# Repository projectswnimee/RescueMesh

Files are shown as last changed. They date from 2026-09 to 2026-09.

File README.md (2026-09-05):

<div align="center">

# RescueMesh

**ESP32 and LoRa emergency messaging for flood and disaster response**

**Semi-finalist — SL IoT competition, Sri Lanka**






</div>

<p align="center">
  <a href="docs/images/rescuemesh-prototype.png">
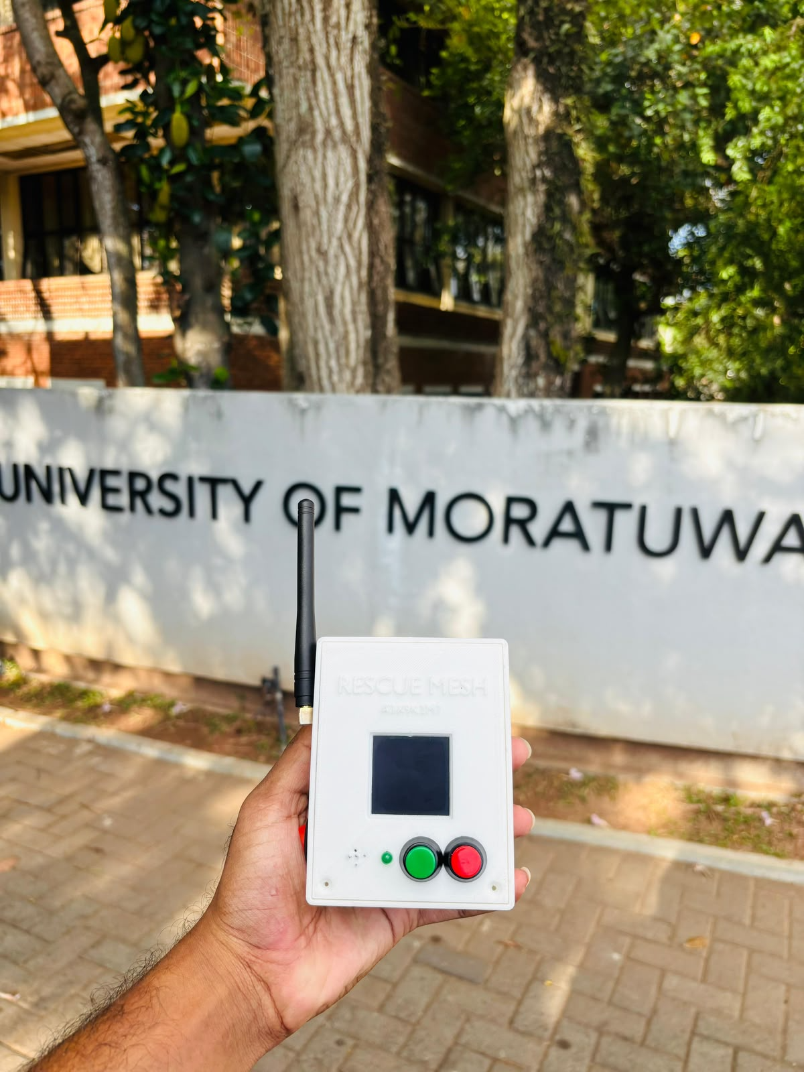
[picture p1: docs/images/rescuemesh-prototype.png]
RescueMesh handheld prototype with antenna, display and control buttons
    
  </a>
  <br>
  <sub>Original prototype photograph supplied by project collaborator Nimesha Nanayakkara. Click to view full size.</sub>
</p>

RescueMesh explores how battery-powered nodes can exchange SOS messages when
normal connectivity is unavailable. ESP32 controllers communicate through
AS32-TTL-100 LoRa radios, with progressive experiments covering broadcast,
relay forwarding, duplicate suppression, TTL and gateway uploads.

This is Nimesha Nanayakkara's maintained copy of the collaborative project.
The [original team repository](https://github.com/HiranGeeth/RescueMesh-Disaster-Rescue_Long-Range-Communication-System),
original MIT licence and hardware-author credits are preserved through explicit
[source attribution](ATTRIBUTION.md).

## System overview

```text
SOS button / Bluetooth input
            ↓
ESP32 field node ↔ LoRa relay nodes ↔ gateway receiver
                                           ↓
                                  Wi-Fi → test backend

Power-path PCB + battery supply + enclosure support the node hardware.
```

The checked-in firmware implements custom messaging over LoRa modules.
An operational LoRaWAN network server and LoRaWAN compliance are not demonstrated.

## Included implementation

| Area | Source and assets |
|---|---|
| Firmware experiments | [test_codes/](test_codes/) — UART, parameter configuration, point-to-point and broadcast messaging |
| Relay behaviour | Deduplication, time windows, TTL, randomized retransmission and rebroadcast tests |
| User interaction | SOS button handling and Bluetooth-to-node experiments |
| Gateway integration | LoRa reception and Wi-Fi upload to a configurable test endpoint |
| Power electronics | [Power-path circuit](hardware/Power%20Path%20Management%20Circuit/) — KiCad schematic/PCB, circuit image and fabrication PDFs |
| Mechanical design | [Enclosure](hardware/Enclosure/) — Blender, STL, Cura and printer-specific G-code assets |
| Coverage studies | [MATLAB simulations](matlab_simulations/) — terrain, coverage and routing experiments |

## Hardware design previews

<p align="center">
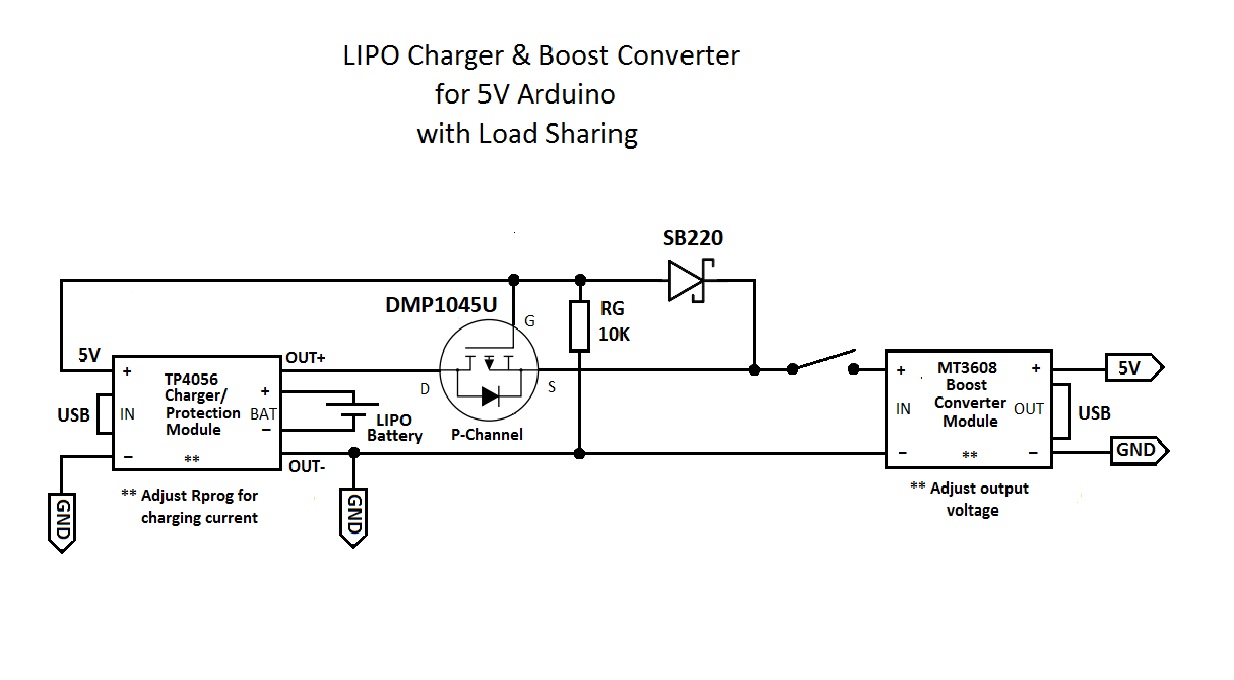
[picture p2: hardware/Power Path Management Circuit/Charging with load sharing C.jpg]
RescueMesh power-path circuit design
  
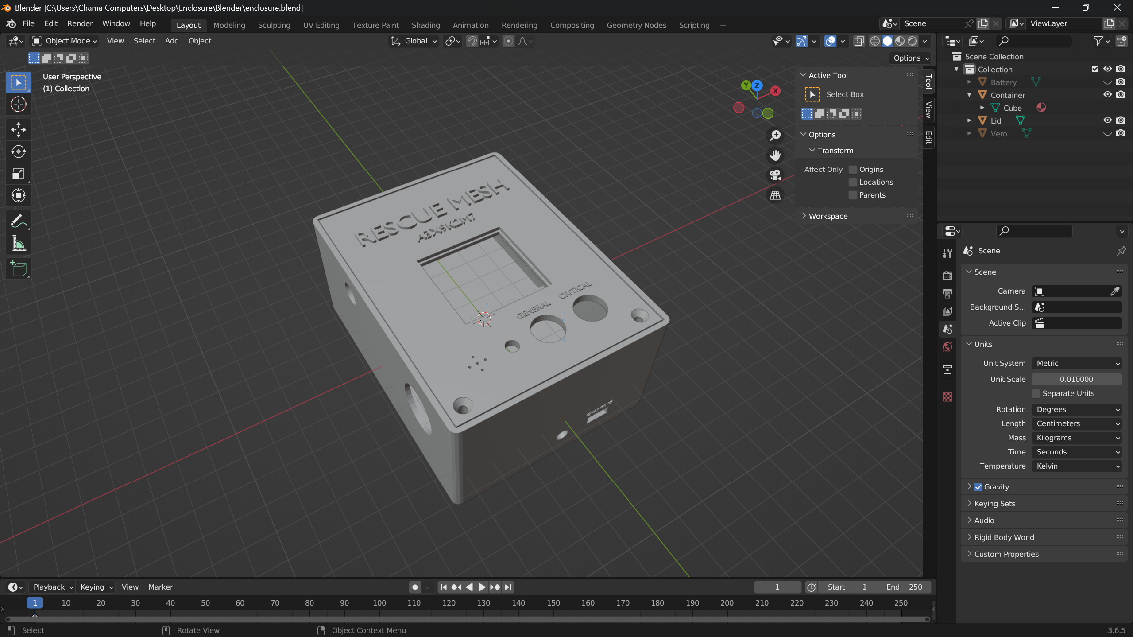
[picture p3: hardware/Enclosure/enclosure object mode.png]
RescueMesh enclosure design preview
  
</p>

These are design assets. The power-path and enclosure documentation credits
**Lasindu Viduranga**. The photograph above documents the assembled prototype;
calibrated power measurements and repeatable field-range data still need to
be added with their test conditions.

## Getting started

1. Clone this repository:

   ```bash
   git -c core.longpaths=true clone https://github.com/projectswnimee/RescueMesh.git
   ```

2. Use Arduino IDE with the ESP32 board support installed. Choose the board
   matching your ESP32 development module.
3. Start with [the GPIO/UART test](test_codes/Code_1.0_GPIO_UART_Test/1.0_GPIO_UART_Test.ino).
   Read the selected sketch's pin definitions before connecting the radio.
4. Progress through parameter read/write and point-to-point tests before using
   relay or field-node sketches. Match radio channel and air settings at both ends.
5. For the gateway upload test, copy
   [secrets.example.h](test_codes/Code_1.3.2.1_Gateway_Backend_Upload_Test/Reciever_Code/secrets.example.h)
   to `secrets.h` in the same sketch folder and enter your own Wi-Fi and endpoint
   values. That local file is ignored by Git.
6. Record the sketch, board package version, wiring, settings and serial logs
   with each experiment. Test one transmitter/receiver pair before adding relays.

The original directories and sketch filenames are retained for traceability.
Arduino IDE may offer to create a matching sketch folder for older filenames.

For `matlab_simulations/DEM.m`, set `OPENTOPOGRAPHY_API_KEY` in your local
environment if downloading new terrain data. Do not commit or print the key.

## Evidence and limits

- **Competition:** semi-finalist in the SL IoT competition, Sri Lanka, reported
  by project collaborator Nimesha Nanayakkara. The edition/year and official
  certificate or announcement are pending addition; see [attribution](ATTRIBUTION.md).
- **Radio:** range and power depend on antennas, configuration, environment and
  board design. Source claims such as 3 km or microamp sleep current are not
  presented here as independently measured whole-system results.
- **Security:** the field-node sketch contains a public demonstration key
  whitelist. This does not establish cryptographic authentication or confidentiality;
  an upstream filename containing “Encryption” is not evidence of secure encryption.
- **Readiness:** folder names such as `Production_Firmware` are inherited source
  labels. This copy has not been newly tested on physical hardware, and is not
  a certified emergency-response system.
- **Simulation:** terrain inputs and MATLAB outputs need their own provenance
  and validation; a coverage simulation does not establish field coverage.

## Collaboration and licence

Use branches and pull requests for new contributions. State your engineering
role and attach relevant measurements or design files. Uploading the shared
source does not confer sole authorship of the project.

See [ATTRIBUTION.md](ATTRIBUTION.md) for the source revision, documented
contributors and publication changes. The original [MIT licence](LICENSE)
and its copyright notice are retained unchanged.

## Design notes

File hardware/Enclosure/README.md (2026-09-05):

# 🧱 3D Printed Enclosure  
## Power Path Management Circuit Housing  

---

## 📌 Description
This enclosure is designed to securely house the **Power Path Management Circuit**, including the LiPo charger, boost converter, and related components.

### ✅ Key Features
- Physical protection  
- Compact organization of components  
- Easy access for USB input and output connections  

---

## 📁 Folder Structure
- **Blender File/** → Original `.blend` design file  
- **Stl/** → STL files for 3D printing  
- **Cura/** → Slicing files / configurations  
- **enclosure object mode.png** → Preview image of the enclosure  

---

## 🛠️ Design Details
- Designed using **Blender**  
- Optimized for **3D printing**  
- Compact and lightweight structure  

### 🔌 Openings
- USB input  
- 5V output  
- Ventilation (if applicable)  

---

## 🖨️ Printing Instructions
- **File format:** `.stl`  
- **Recommended material:** PLA  

### ⚙️ Suggested Settings
- Layer height: 0.2 mm  
- Infill: 20–40%  
- Supports: As required (depending on orientation)  

---

## ⚠️ Notes
- Ensure proper alignment before printing  
- Check tolerances based on your printer accuracy  
- Modify design if your components differ in size  

---

## 🧠 Applications
- Embedded systems enclosure  
- Arduino / IoT projects  
- Portable electronics housing  

---

## 👨‍💻 Author
**Lasindu Viduranga**  
📧 wplvidu@gmail.com  

**Team Member**  
Rescue Mesh

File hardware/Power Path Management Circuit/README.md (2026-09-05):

# 🔋 Power Path Management Circuit  
## LiPo Charger + Boost Converter with Load Sharing (5V Output)

---

## 📌 Description
This module implements a **power path management system** that allows a device (e.g., Arduino, ESP32) to be powered while simultaneously charging a LiPo battery.

### ✅ Key Features
- Safe battery charging  
- Automatic load sharing between USB input and battery  
- Stable 5V output using a boost converter  

---

## ⚙️ How It Works
- The **TP4056 module** charges the LiPo battery from a 5V USB input  
- A **P-channel MOSFET (DMP1045U)** controls power flow  

### 🔌 Operation Modes
**When USB is connected:**
- Load is powered directly from USB  
- Battery charges simultaneously  

**When USB is disconnected:**
- Battery supplies power to the load  

- The **MT3608 boost converter** steps battery voltage up to a stable **5V output**

---

## 🧩 Components Used
- TP4056 LiPo Charger Module (with protection)  
- LiPo Battery (3.7V)  
- DMP1045U P-Channel MOSFET  
- SB220 Schottky Diode  
- 10kΩ Resistor  
- MT3608 Boost Converter Module  

---

## 📁 Files Included
- **schematics/** → Circuit diagram files  
- **pcb/** → PCB design files (Gerber, layout)  

---

## 🔌 Input & Output
- **Input:** 5V (USB)  
- **Battery:** 3.7V LiPo  
- **Output:** Regulated 5V  

---

## ⚠️ Notes
- Adjust **Rprog** on TP4056 to set charging current  
- Adjust **MT3608** to get exact 5V output before connecting load  
- Ensure proper heat dissipation for high current usage  

---

## 🧠 Applications
- Arduino & Embedded Systems  
- Portable electronics  
- IoT devices with battery backup  

---

## 👨‍💻 Author
**Lasindu Viduranga**  
📧 wplvidu@gmail.com  

**Team Member**  
Rescue Mesh

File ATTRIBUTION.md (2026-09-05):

# Source and contributions

RescueMesh is collaborative engineering work. This repository is maintained by
Nimesha Nanayakkara (`projectswnimee`) as an authorized project copy.

## Original source

- [Team repository](https://github.com/HiranGeeth/RescueMesh-Disaster-Rescue_Long-Range-Communication-System)
- Imported source revision: `a151df3` (see the upstream history for full authorship)
- Original [MIT licence](LICENSE): copyright 2025 Hiran Geeth, preserved unchanged

The upstream commit history credits Hiran Geeth / Hiran Geeth Dharmapala and
Lasindu Viduranga. The hardware documentation explicitly credits Lasindu
Viduranga for the power-path circuit and enclosure work. Those credits remain
in their original files.

## This publication

This repository starts with a reviewed source snapshot instead of copying the
upstream history, which contains hard-coded credentials. The publication work
covers README organization, source attribution, local-configuration examples,
and competition recognition. A new import commit does not imply sole authorship
of the firmware, PCB, enclosure or simulations.

Individual engineering roles beyond those documented above will be recorded
when confirmed by the team. No roles have been assigned based on who uploaded
the repository.

## Recognition

Semi-finalist in the SL IoT competition, Sri Lanka, as reported by project
collaborator Nimesha Nanayakkara. The edition/year and certificate or official
announcement are not yet included in this repository.

## Publication changes

- Replaced Wi-Fi credentials and a webhook endpoint with an ignored local
  `secrets.h` and a committed `secrets.example.h` template.
- Replaced the field-node key whitelist with clearly labelled demonstration keys.
- Moved the terrain-download API key to `OPENTOPOGRAPHY_API_KEY` in the local environment.
- Retained the original source folders and hardware design assets.
- Excluded local KiCad preference/cache files through `.gitignore`.
- Corrected the project description to distinguish custom LoRa messaging from
  a verified LoRaWAN implementation, and separated design claims from measurements.

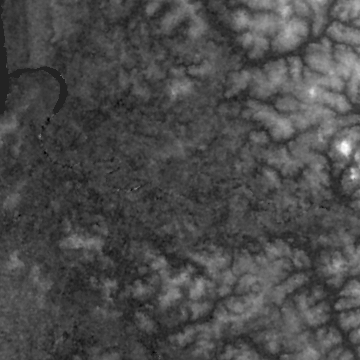
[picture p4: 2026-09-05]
matlab_simulations/DEM_SRTMGL1.tif

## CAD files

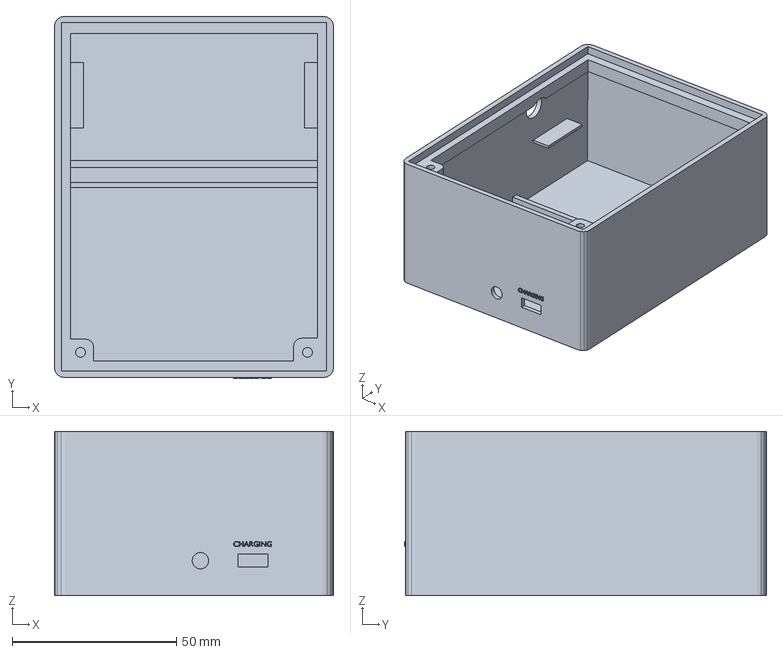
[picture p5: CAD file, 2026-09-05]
hardware/Enclosure/Cura/container.3mf
85.0 x 110.4 x 50.0 mm

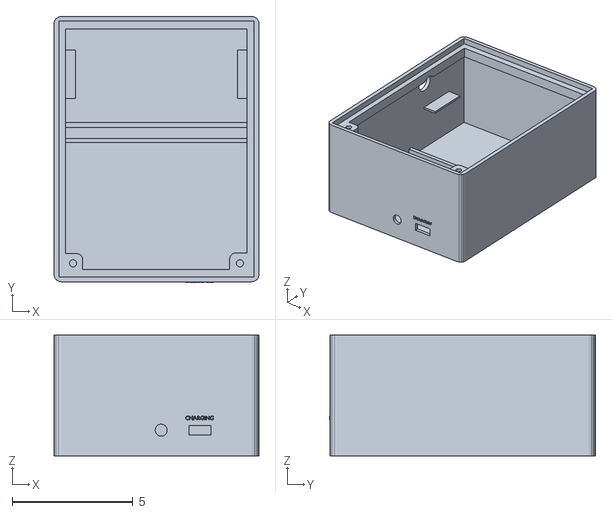
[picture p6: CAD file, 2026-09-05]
hardware/Enclosure/Stl/container.stl
8.50 x 11.0 x 5.00

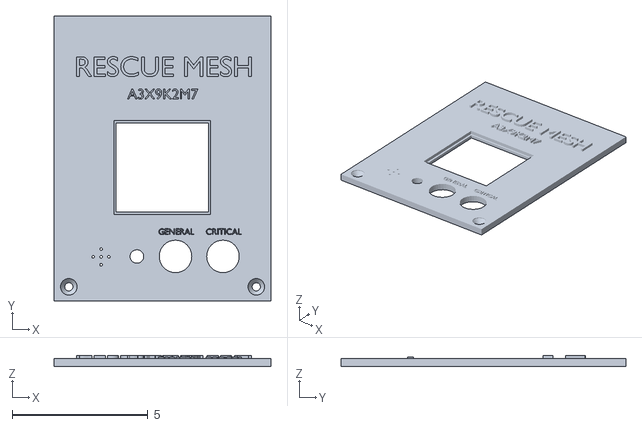
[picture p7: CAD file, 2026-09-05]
hardware/Enclosure/Stl/lid.stl
8.00 x 10.5 x 0.417

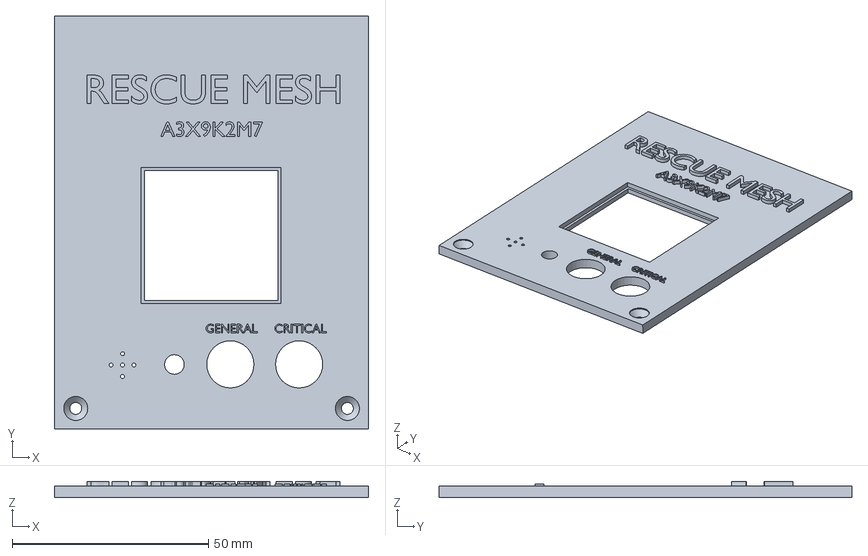
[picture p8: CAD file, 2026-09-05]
hardware/Enclosure/Cura/lid.3mf
80.0 x 105.1 x 4.17 mm

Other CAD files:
hardware/Enclosure/Cura/CE3V3SE_container v2.3mf
hardware/Enclosure/Stl/container v2.stl
hardware/Enclosure/Blender File/enclosure.blend

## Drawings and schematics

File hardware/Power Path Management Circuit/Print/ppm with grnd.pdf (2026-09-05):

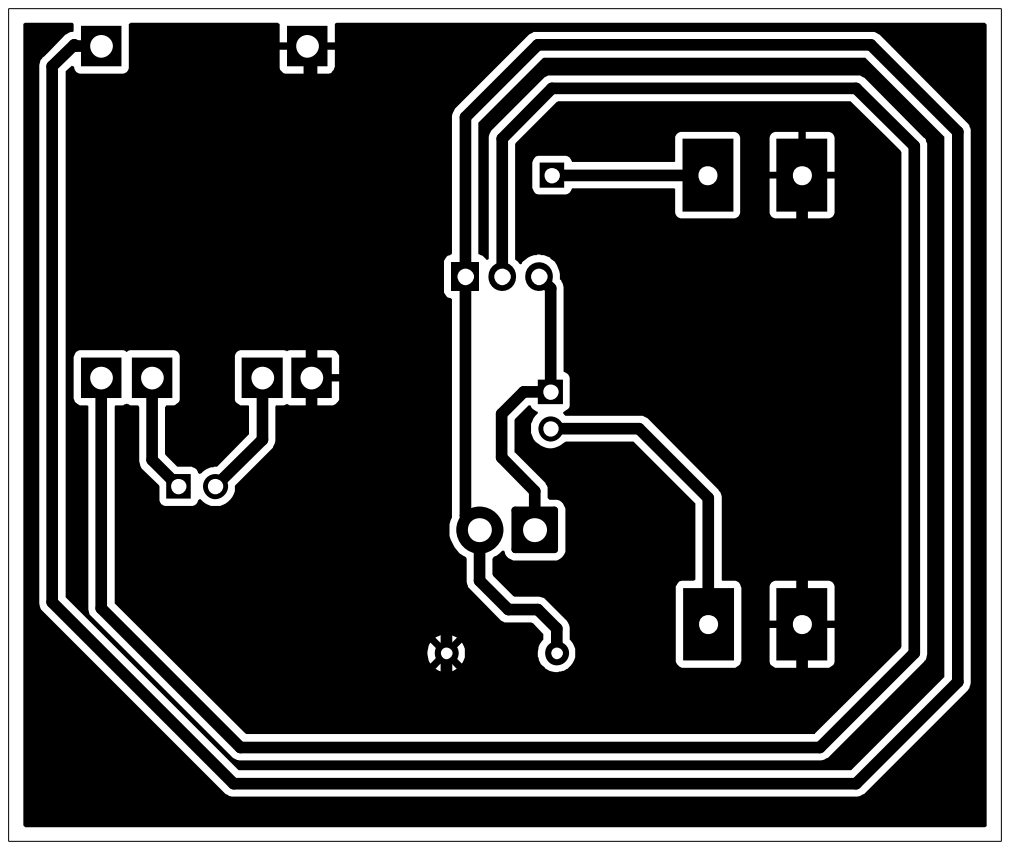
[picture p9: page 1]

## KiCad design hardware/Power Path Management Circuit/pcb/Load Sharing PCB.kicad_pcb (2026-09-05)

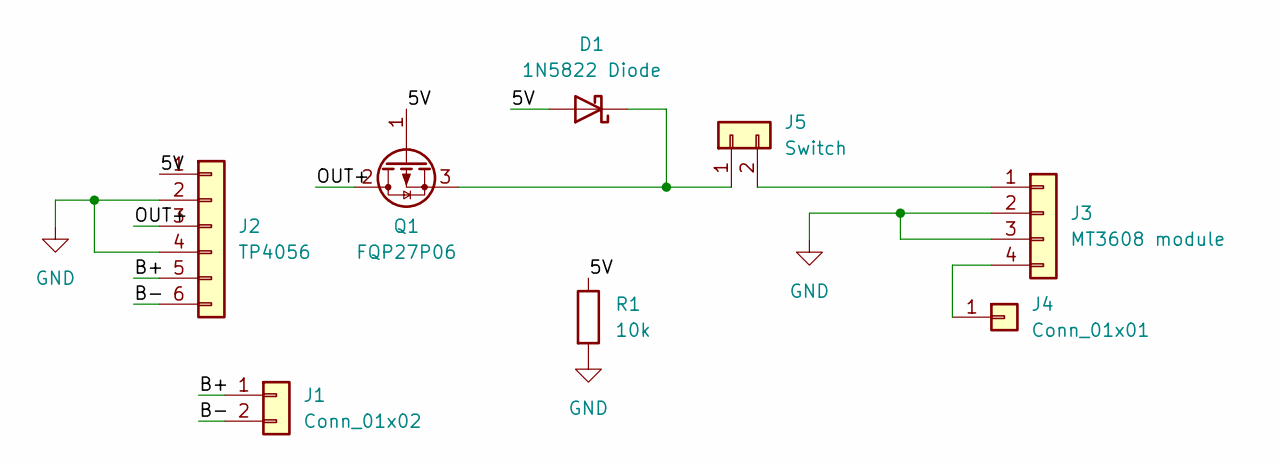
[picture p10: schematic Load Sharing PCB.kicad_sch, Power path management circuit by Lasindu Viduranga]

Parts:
D1: 1N5822 Diode; D_DO-201AD_P3.81mm_Vertical_AnodeUp
J1: Conn_01x02; PinHeader_1x02_P2.54mm_Vertical
J2: TP4056; TP4056-18650
J3: MT3608 module; MT3608_module
J4: Conn_01x01; PinHeader_1x01_P2.54mm_Vertical
J5: Switch; PinHeader_1x02_P2.54mm_Horizontal
Q1: FQP27P06; TO-220-3_Vertical
R1: 10k; R_Axial_DIN0207_L6.3mm_D2.5mm_P7.62mm_Horizontal

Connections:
/5V: D1.2 (A), J2.1, Q1.1 (G), R1.1
/B+: J1.1, J2.5
/B-: J1.2, J2.6
/OUT+: J2.3, Q1.2 (D)
GND: J2.2, J2.4, J3.2, J3.3, R1.2
unnamed: D1.1 (K), J5.1, Q1.3 (S)
unnamed: J3.1, J5.2
unnamed: J3.4, J4.1

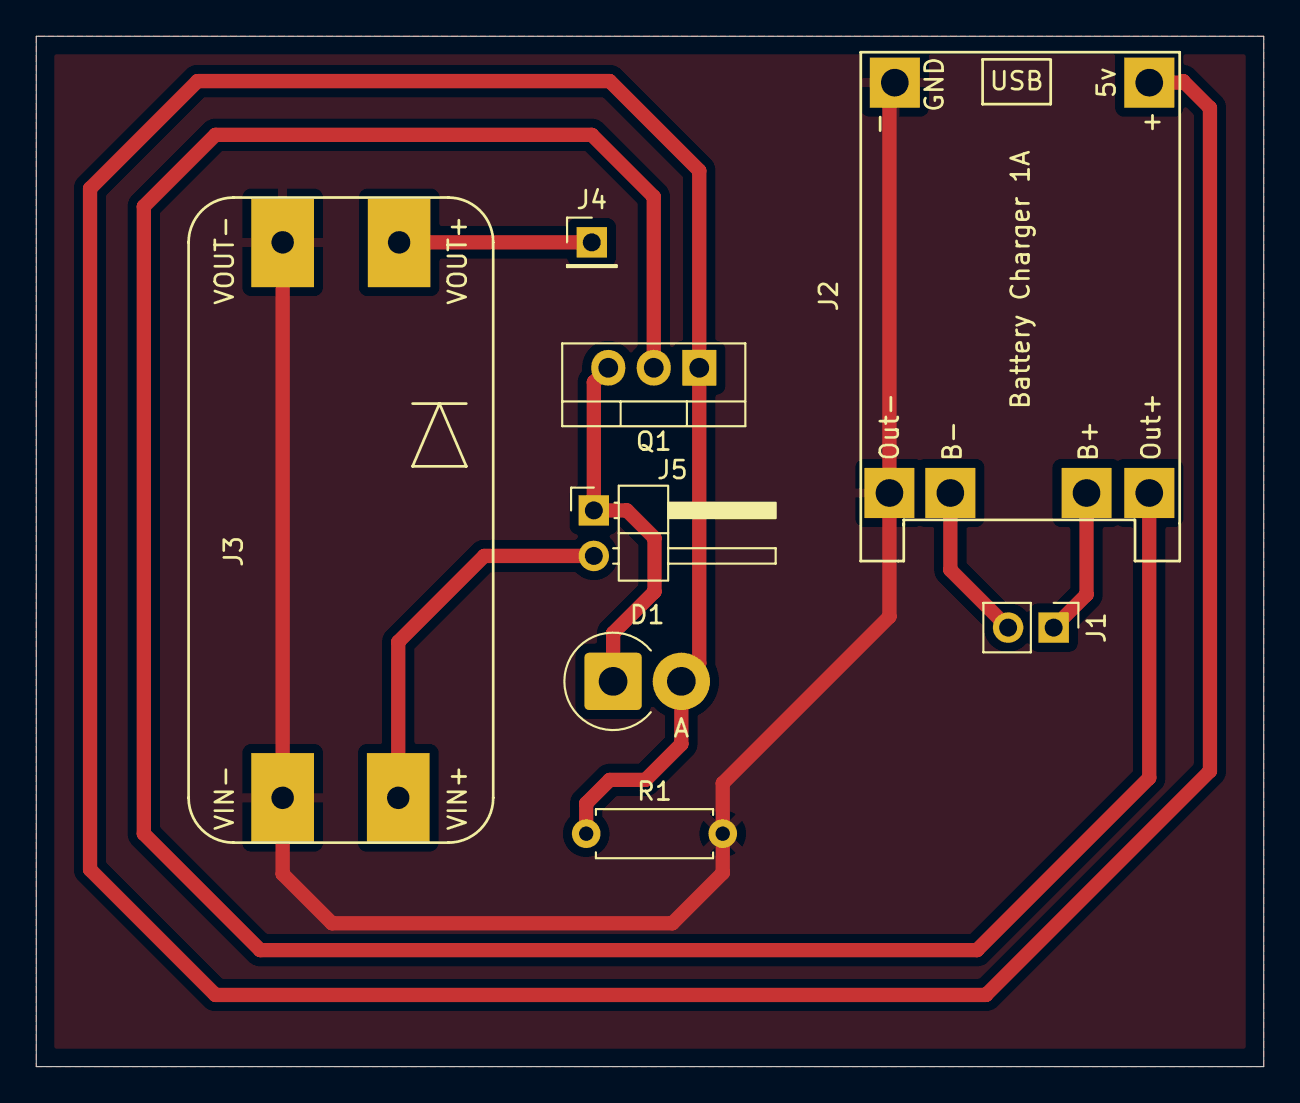
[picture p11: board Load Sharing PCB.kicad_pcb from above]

Board: 2 copper layers, 68.5 x 57.5 mm, 8 parts (0 on the bottom side), 8 nets.

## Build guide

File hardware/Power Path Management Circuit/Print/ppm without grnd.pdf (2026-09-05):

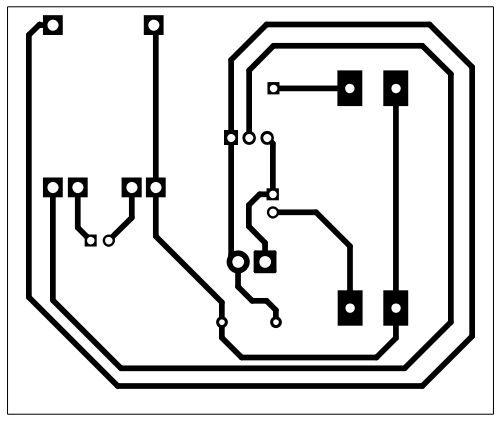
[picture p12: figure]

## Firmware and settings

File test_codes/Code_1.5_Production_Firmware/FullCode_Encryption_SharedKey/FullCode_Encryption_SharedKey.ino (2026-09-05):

/* ============================================================
   FloodGuard AIoT — Field Node v4.3 (SIMPLE BUTTON PRESS)
   ============================================================
   BEHAVIOR:
   - GENERAL button: Press once → sends ONE alert
   - CRITICAL button: Press once → sends ONE alert
   - NO auto-repeat, NO toggle mode
   - Each press sends exactly ONE message
   ============================================================ */

#include <Arduino.h>
#include "BluetoothSerial.h"
#include <EEPROM.h>

/* ================= PINOUT ================= */
#define LORA_TX       17
#define LORA_RX       16
#define LORA_MD0      25
#define LORA_MD1      26
#define BTN_GENERAL   33
#define BTN_CRITICAL  32
#define LED_STATUS    2
#define LED_REPLY     4

HardwareSerial LoRaSerial(2);
BluetoothSerial SerialBT;

/* ================= DEMONSTRATION WHITELIST ================= */
// Public examples only. These identifiers do not provide secure authentication.
const String VALID_KEYS[] = {
  "DEMO0001",   // NODE 01
  "DEMO0002",   // NODE 02
  "DEMO0003",   // NODE 03
  "DEMO0004",   // NODE 04
  "DEMO0005"    // NODE 05
};
const int VALID_KEY_COUNT = 5;

/* ================= NODE CONFIG ================= */
String NODE_KEY = "";
String NODE_NUMBER = "";
bool NODE_REGISTERED = false;
String LATITUDE = "6.9271";
String LONGITUDE = "79.8612";

// EEPROM addresses
#define EEPROM_KEY_ADDR    0
#define EEPROM_KEY_LEN     16
#define EEPROM_REG_FLAG    32

/* ================= MESSAGE CONFIG ================= */
uint8_t seqCounter = 1;
const int DEFAULT_TTL = 5;

/* ================= BUFFERS ================= */
String rxBuffer = "";

/* ================= DEDUP ================= */
String dedupList[30];
uint8_t dedupIndex = 0;

/* ================= BUTTON STATE ================= */
bool lastGeneralState = HIGH;
bool lastCriticalState = HIGH;

/* ================= DEBOUNCE ================= */
unsigned long lastGeneralDebounce = 0;
unsigned long lastCriticalDebounce = 0;
const unsigned long DEBOUNCE_DELAY = 200;

/* ================= LED PATTERNS ================= */
enum LEDPattern {
  LED_NORMAL,
  LED_SENDING,
  LED_REPLY_RECEIVED,
  LED_INTRUDER
};
LEDPattern currentPattern = LED_NORMAL;
unsigned long lastLedBlink = 0;
int intruderCount = 0;

/* ============================================================
   KEY VALIDATION
   ============================================================ */

bool isValidNodeKey(String key) {
  for (int i = 0; i < VALID_KEY_COUNT; i++) {
    if (VALID_KEYS[i] == key) return true;
  }
  return false;
}

void logIntruder(String key) {
  intruderCount++;
  Serial.println("╔═══════════════════════════════════════╗");
  Serial.println("║   ⚠️ INTRUDER ALERT ⚠️                 ║");
  Serial.println("╠═══════════════════════════════════════╣");
  Serial.print("║ INVALID KEY: ");
  Serial.println(key);
  Serial.print("║ COUNT:       ");
  Serial.println(String(intruderCount));
  Serial.println("╚═══════════════════════════════════════╝");
  currentPattern = LED_INTRUDER;
  lastLedBlink = millis();
}

/* ============================================================
   SYMBOL ENCRYPTION/DECRYPTION
   ============================================================ */

String encryptPayload(String plain) {
  String encrypted = "";
  for (int i = 0; i < plain.length(); i++) {
    char c = plain.charAt(i);
    switch (c) {
      case 'A': case 'a': encrypted += "@!"; break;
      case 'B': case 'b': encrypted += "#$"; break;
      case 'C': case 'c': encrypted += "%^"; break;
      case 'D': case 'd': encrypted += "&*"; break;
      case 'E': case 'e': encrypted += "(-"; break;
      case 'F': case 'f': encrypted += ")+"; break;
      case 'G': case 'g': encrypted += "[="; break;
      case 'H': case 'h': encrypted += "]{"; break;
      case 'I': case 'i': encrypted += "}|"; break;
      case 'J': case 'j': encrypted += "\\:"; break;
      case 'K': case 'k': encrypted += ";'"; break;
      case 'L': case 'l': encrypted += "\"<"; break;
      case 'M': case 'm': encrypted += ">?"; break;
      case 'N': case 'n': encrypted += "/~"; break;
      case 'O': case 'o': encrypted += "`1"; break;
      case 'P': case 'p': encrypted += "2@"; break;
      case 'Q': case 'q': encrypted += "3#"; break;
      case 'R': case 'r': encrypted += "4$"; break;
      case 'S': case 's': encrypted += "5%"; break;
      case 'T': case 't': encrypted += "6^"; break;
      case 'U': case 'u': encrypted += "7&"; break;
      case 'V': case 'v': encrypted += "8*"; break;
      case 'W': case 'w': encrypted += "9("; break;
      case 'X': case 'x': encrypted += "0)"; break;
      case 'Y': case 'y': encrypted += "-="; break;
      case 'Z': case 'z': encrypted += "+="; break;
      case '0': encrypted += "aa"; break;
      case '1': encrypted += "bb"; break;
      case '2': encrypted += "cc"; break;
      case '3': encrypted += "dd"; break;
      case '4': encrypted += "ee"; break;
      case '5': encrypted += "ff"; break;
      case '6': encrypted += "gg"; break;
      case '7': encrypted += "hh"; break;
      case '8': encrypted += "ii"; break;
      case '9': encrypted += "jj"; break;
      case '!': encrypted += "kk"; break;
      case '?': encrypted += "ll"; break;
      case '.': encrypted += "mm"; break;
      case ',': encrypted += "nn"; break;
      case ':': encrypted += "oo"; break;
      case ';': encrypted += "pp"; break;
      case ' ': encrypted += "**"; break;
      default:  encrypted += "??"; break;
    }
  }
  return encrypted;
}

String decryptPayload(String enc) {
  String decrypted = "";
  for (int i = 0; i + 1 < enc.length(); i += 2) {
    String sym = enc.substring(i, i + 2);
    if      (sym == "@!") decrypted += "A";
    else if (sym == "#$") decrypted += "B";
    else if (sym == "%^") decrypted += "C";
    else if (sym == "&*") decrypted += "D";
    else if (sym == "(-") decrypted += "E";
    else if (sym == ")+") decrypted += "F";
    else if (sym == "[=") decrypted += "G";
    else if (sym == "]{") decrypted += "H";
    else if (sym == "}|") decrypted += "I";
    else if (sym == "\\:") decrypted += "J";
    else if (sym == ";'") decrypted += "K";
    else if (sym == "\"<") decrypted += "L";
    else if (sym == ">?") decrypted += "M";
    else if (sym == "/~") decrypted += "N";
    else if (sym == "`1") decrypted += "O";
    else if (sym == "2@") decrypted += "P";
    else if (sym == "3#") decrypted += "Q";
    else if (sym == "4$") decrypted += "R";
    else if (sym == "5%") decrypted += "S";
    else if (sym == "6^") decrypted += "T";
    else if (sym == "7&") decrypted += "U";
    else if (sym == "8*") decrypted += "V";
    else if (sym == "9(") decrypted += "W";
    else if (sym == "0)") decrypted += "X";
    else if (sym == "-=") decrypted += "Y";
    else if (sym == "+=") decrypted += "Z";
    else if (sym == "aa") decrypted += "0";
    else if (sym == "bb") decrypted += "1";
    else if (sym == "cc") decrypted += "2";
    else if (sym == "dd") decrypted += "3";
    else if (sym == "ee") decrypted += "4";
    else if (sym == "ff") decrypted += "5";
    else if (sym == "gg") decrypted += "6";
    else if (sym == "hh") decrypted += "7";
    else if (sym == "ii") decrypted += "8";
    else if (sym == "jj") decrypted += "9";
    else if (sym == "kk") decrypted += "!";
    else if (sym == "ll") decrypted += "?";
    else if (sym == "mm") decrypted += ".";
    else if (sym == "nn") decrypted += ",";
    else if (sym == "oo") decrypted += ":";
    else if (sym == "pp") decrypted += ";";
    else if (sym == "**") decrypted += " ";
    else                  decrypted += "?";
  }
  return decrypted;
}

/* ============================================================
   EEPROM STORAGE
   ============================================================ */

void saveNodeToEEPROM() {
  for (int i = 0; i < EEPROM_KEY_LEN; i++) {
    EEPROM.write(EEPROM_KEY_ADDR + i, 0);
  }
  for (int i = 0; i < NODE_KEY.length() && i < EEPROM_KEY_LEN; i++) {
    EEPROM.write(EEPROM_KEY_ADDR + i, NODE_KEY[i]);
  }
  EEPROM.write(EEPROM_REG_FLAG, 1);
  EEPROM.commit();
  Serial.print("[EEPROM] Node key saved: ");
  Serial.println(NODE_KEY);
}

void loadNodeFromEEPROM() {
  EEPROM.begin(512);
  byte registered = EEPROM.read(EEPROM_REG_FLAG);
  
  if (registered == 1) {
    char keyBuf[EEPROM_KEY_LEN + 1];
    bool hasValidKey = false;
    
    for (int i = 0; i < EEPROM_KEY_LEN; i++) {
      char c = EEPROM.read(EEPROM_KEY_ADDR + i);
      if (c >= 'A' && c <= 'Z' || c >= '0' && c <= '9') {
        keyBuf[i] = c;
        hasValidKey = true;
      } else {
        keyBuf[i] = '\0';
        break;
      }
    }
    keyBuf[EEPROM_KEY_LEN] = '\0';
    
    if (hasValidKey && String(keyBuf).length() >= 6) {
      NODE_KEY = String(keyBuf);
      NODE_NUMBER = "Node_" + NODE_KEY.substring(0, 4);
      NODE_REGISTERED = true;
      Serial.print("✓ Loaded from EEPROM: ");
      Serial.println(NODE_KEY);
    } else {
      NODE_REGISTERED = false;
    }
  }
}

/* ============================================================
   REGISTRATION
   ============================================================ */

void registerNode() {
  Serial.println("\n╔═══════════════════════════════════════╗");
  Serial.println("║   NODE NOT REGISTERED                 ║");
  Serial.println("║   Valid keys:                         ║");
  for (int i = 0; i < VALID_KEY_COUNT; i++) {
    Serial.print("║     ");
    Serial.println(VALID_KEYS[i]);
  }
  Serial.println("║                                       ║");
  Serial.println("║   Enter 8-char key from above:        ║");
  Serial.println("╚═══════════════════════════════════════╝");
  Serial.print("Enter key: ");
  
  unsigned long startTime = millis();
  String inputKey = "";
  bool inputComplete = false;
  
  while (millis() - startTime < 60000) {
    if (Serial.available()) {
      char c = Serial.read();
      if (c == '\n' || c == '\r') {
        if (inputKey.length() > 0) {
          inputComplete = true;
          break;
        }
      } else if ((c >= 'A' && c <= 'Z') || (c >= '0' && c <= '9')) {
        inputKey += c;
        Serial.print(c);
      }
    }
    delay(10);
  }
  
  if (inputComplete && isValidNodeKey(inputKey)) {
    NODE_KEY = inputKey;
    NODE_NUMBER = "Node_" + NODE_KEY.substring(0, 4);
    NODE_REGISTERED = true;
    saveNodeToEEPROM();
    
    Serial.println();
    Serial.println("✓ Registration successful!");
    Serial.print("  KEY: ");
    Serial.println(NODE_KEY);
    Serial.print("  NAME: ");
    Serial.println(NODE_NUMBER);
    delay(2000);
  } else {
    Serial.println();
    Serial.println("✗ Invalid key! Restart to try again.");
    while(1) {
      digitalWrite(LED_STATUS, HIGH);
      delay(200);
      digitalWrite(LED_STATUS, LOW);
      delay(200);
    }
  }
}

/* ============================================================
   BLUETOOTH SETUP
   ============================================================ */

void setupBluetooth() {
  String btName = "FloodGuard_User";
  
  if (NODE_REGISTERED && NODE_KEY.length() > 0) {
    String uniqueId = NODE_KEY.substring(NODE_KEY.length() - 4);
    btName = "FloodGuard_" + uniqueId;
  }
  
  SerialBT.begin(btName);
  
  Serial.print("[BLUETOOTH] Name: ");
  Serial.println(btName);
  Serial.println("[BLUETOOTH] Ready to pair. No PIN required.");
}

/* ============================================================
   LED STATUS
   ============================================================ */

void updateLED() {
  unsigned long now = millis();
  
  switch (currentPattern) {
    case LED_NORMAL:
      digitalWrite(LED_STATUS, HIGH);
      digitalWrite(LED_REPLY, LOW);
      break;
      
    case LED_SENDING:
      if (now - lastLedBlink < 100) digitalWrite(LED_STATUS, HIGH);
      else if (now - lastLedBlink < 200) digitalWrite(LED_STATUS, LOW);
      else lastLedBlink = now;
      break;
      
    case LED_REPLY_RECEIVED:
      if (now - lastLedBlink < 500) {
        digitalWrite(LED_STATUS, HIGH);
        digitalWrite(LED_REPLY, HIGH);
      } else if (now - lastLedBlink < 1000) {
        digitalWrite(LED_STATUS, LOW);
        digitalWrite(LED_REPLY, LOW);
      } else {
        currentPattern = LED_NORMAL;
      }
      break;
      
    case LED_INTRUDER:
      if (now - lastLedBlink < 100) digitalWrite(LED_STATUS, HIGH);
      else if (now - lastLedBlink < 200) digitalWrite(LED_STATUS, LOW);
      else if (now - lastLedBlink < 300) digitalWrite(LED_STATUS, HIGH);
      else if (now - lastLedBlink < 400) digitalWrite(LED_STATUS, LOW);
      else lastLedBlink = now;
      break;
  }
}

/* ============================================================
   DISPLAY REPLY
   ============================================================ */

void displayReply(String decryptedMessage, String msgId) {
  currentPattern = LED_REPLY_RECEIVED;
  lastLedBlink = millis();
  
  Serial.println("\n");
  Serial.println("╔══════════════════════════════════════════════════════════════╗");
  Serial.println("║                    📨 REPLY FROM RESCUE TEAM                  ║");
  Serial.println("╠══════════════════════════════════════════════════════════════╣");
  Serial.print("║ MSG ID:     ");
  Serial.println(msgId);
  Serial.print("║ TO NODE:    ");
  Serial.print(NODE_KEY);
  Serial.print(" (");
  Serial.print(NODE_NUMBER);
  Serial.println(")");
  Serial.println("╠══════════════════════════════════════════════════════════════╣");
  Serial.println("║ MESSAGE:                                                    ║");
  
  String remaining = decryptedMessage;
  while (remaining.length() > 50) {
    Serial.print("║ ");
    Serial.println(remaining.substring(0, 50));
    remaining = remaining.substring(50);
  }
  if (remaining.length() > 0) {
    Serial.print("║ ");
    Serial.println(remaining);
  }
  
  Serial.println("╚══════════════════════════════════════════════════════════════╝");
  Serial.println();
  
  if (SerialBT.hasClient()) {
    SerialBT.print("REPLY: ");
    SerialBT.println(decryptedMessage);
  }
}

/* ============================================================
   DEDUP
   ============================================================ */

bool isDuplicate(String id) {
  for (int i = 0; i < 30; i++) {
    if (dedupList[i] == id) return true;
  }
  return false;
}

void storeDedupID(String id) {
  dedupList[dedupIndex] = id;
  dedupIndex = (dedupIndex + 1) % 30;
}

/* ============================================================
   SEND MESSAGE
   ============================================================ */

void sendLoRaMessage(String payload, String flag) {
  if (!NODE_REGISTERED) {
    Serial.println("[ERROR] Node not registered!");
    return;
  }
  
  currentPattern = LED_SENDING;
  lastLedBlink = millis();
  
  String seqStr = (seqCounter < 10) ? "0" + String(seqCounter) : String(seqCounter);
  seqCounter++;
  
  String encPayload = encryptPayload(payload);
  
  String fullMsg = "FG|" + NODE_KEY + "|" + seqStr + "|" + 
                   String(DEFAULT_TTL) + "|" + NODE_KEY + "|" +
                   flag + "|" + LATITUDE + "|" + LONGITUDE + "|" +
                   encPayload + "\n";
  
  LoRaSerial.write(fullMsg.c_str(), fullMsg.length());
  
  Serial.println("────────────────────────────────────────");
  Serial.print("[SENT] From: ");
  Serial.println(NODE_KEY);
  Serial.print("[FLAG] ");
  Serial.println(flag);
  Serial.print("[MSG ] ");
  Serial.println(payload);
  Serial.println("────────────────────────────────────────");
  
  delay(100);
  currentPattern = LED_NORMAL;
}

/* ============================================================
   BUTTON HANDLERS (SIMPLE — ONE PRESS = ONE MESSAGE)
   ============================================================ */

void handleButtons() {
  unsigned long now = millis();
  
  // Read current button states (LOW = pressed, because INPUT_PULLUP)
  bool currentGeneral = digitalRead(BTN_GENERAL);
  bool currentCritical = digitalRead(BTN_CRITICAL);
  
  // GENERAL BUTTON — Rising edge detection (released after press)
  if (lastGeneralState == LOW && currentGeneral == HIGH) {
    if (now - lastGeneralDebounce > DEBOUNCE_DELAY) {
      lastGeneralDebounce = now;
      sendLoRaMessage("General safety issue reported", "BTN_GENERAL");
      Serial.println("[BTN] GENERAL alert sent");
    }
  }
  lastGeneralState = currentGeneral;
  
  // CRITICAL BUTTON — Rising edge detection (released after press)
  if (lastCriticalState == LOW && currentCritical == HIGH) {
    if (now - lastCriticalDebounce > DEBOUNCE_DELAY) {
      lastCriticalDebounce = now;
      sendLoRaMessage("CRITICAL EMERGENCY SOS", "BTN_CRITICAL");
      Serial.println("[BTN] CRITICAL alert sent");
    }
  }
  lastCriticalState = currentCritical;
}

/* ============================================================
   PROCESS RECEIVED
   ============================================================ */

void processReceived(String raw) {
  raw.trim();
  if (raw.length() == 0) return;
  
  /* ========== HANDLE BACKEND REPLY ========== */
  if (raw.startsWith("FGR|")) {
    int p1 = raw.indexOf('|');
    int p2 = raw.indexOf('|', p1 + 1);
    int p3 = raw.indexOf('|', p2 + 1);
    
    if (p1 > 0 && p2 > p1 && p3 > p2) {
      String destKey = raw.substring(p1 + 1, p2);
      String msgId = raw.substring(p2 + 1, p3);
      String encPayload = raw.substring(p3 + 1);
      encPayload.trim();
      
      if (destKey == NODE_KEY) {
        String decrypted = decryptPayload(encPayload);
        displayReply(decrypted, msgId);
        Serial.println("[REPLY] ✅ For THIS node - DISPLAYED");
        return;
      } else if (isValidNodeKey(destKey)) {
        int delayMs = random(1000, 5001);
        delay(delayMs);
        LoRaSerial.write((raw + "\n").c_str(), raw.length() + 1);
        return;
      }
    }
    return;
  }
  
  /* ========== HANDLE LOCATION UPDATE ========== */
  if (raw.startsWith("LOC|")) {
    int p1 = raw.indexOf('|');
    int p2 = raw.indexOf('|', p1 + 1);
    int p3 = raw.indexOf('|', p2 + 1);
    
    if (p1 > 0 && p2 > p1 && p3 > p2) {
      String destKey = raw.substring(p1 + 1, p2);
      
      if (destKey == NODE_KEY) {
        LATITUDE = raw.substring(p2 + 1, p3);
        LONGITUDE = raw.substring(p3 + 1);
        Serial.print("[LOCATION] Updated: ");
        Serial.print(LATITUDE);
        Serial.print(", ");
        Serial.println(LONGITUDE);
        return;
      } else if (isValidNodeKey(destKey)) {
        int delayMs = random(1000, 5001);
        delay(delayMs);
        LoRaSerial.write((raw + "\n").c_str(), raw.length() + 1);
        return;
      }
    }
    return;
  }
  
  /* ========== HANDLE FIELD MESSAGE ========== */
  if (!raw.startsWith("FG|")) return;
  
  int p1 = raw.indexOf('|');
  int p2 = raw.indexOf('|', p1 + 1);
  int p3 = raw.indexOf('|', p2 + 1);
  int p4 = raw.indexOf('|', p3 + 1);
  int p5 = raw.indexOf('|', p4 + 1);
  int p6 = raw.indexOf('|', p5 + 1);
  int p7 = raw.indexOf('|', p6 + 1);
  int p8 = raw.indexOf('|', p7 + 1);
  
  if (p1 < 0 || p2 < 0 || p3 < 0 || p4 < 0 || p5 < 0 || p6 < 0 || p7 < 0 || p8 < 0) return;
  
  String nodeKey = raw.substring(p1 + 1, p2);
  String seqNo   = raw.substring(p2 + 1, p3);
  int    ttl     = raw.substring(p3 + 1, p4).toInt();
  String path    = raw.substring(p4 + 1, p5);
  String flag    = raw.substring(p5 + 1, p6);
  String lat     = raw.substring(p6 + 1, p7);
  String lon     = raw.substring(p7 + 1, p8);
  String payload = raw.substring(p8 + 1);
  
  if (!isValidNodeKey(nodeKey)) {
    logIntruder(nodeKey);
    return;
  }
  
  if (ttl <= 0) return;
  if (nodeKey == NODE_KEY) return;
  
  String dedupID = nodeKey + seqNo;
  if (isDuplicate(dedupID)) return;
  storeDedupID(dedupID);
  
  String newPath = path + ">" + NODE_KEY;
  int delayMs = random(1000, 5001);
  delay(delayMs);
  
  String relayMsg = "FG|" + nodeKey + "|" + seqNo + "|" +
                    String(ttl - 1) + "|" + newPath + "|" +
                    "RELAY" + "|" + lat + "|" + lon + "|" +
                    payload + "\n";
  
  LoRaSerial.write(relayMsg.c_str(), relayMsg.length());
}

/* ============================================================
   SETUP
   ============================================================ */
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
void loop() {
  handleButtons();
  updateLED();
  
  // Bluetooth input
  if (SerialBT.available()) {
    String btMsg = SerialBT.readStringUntil('\n');
    btMsg.trim();
    if (btMsg.length() > 0 && btMsg.length() < 200) {
      sendLoRaMessage(btMsg, "BT");
      Serial.print("[BT] Sent: ");
      Serial.println(btMsg);
      SerialBT.print("Sent: ");
      SerialBT.println(btMsg);
    }
  }
  
  // Serial input
  if (Serial.available()) {
    String userMsg = Serial.readStringUntil('\n');
    userMsg.trim();
    if (userMsg.length() > 0) {
      if (userMsg == "STATUS") {
        Serial.println("=== NODE STATUS ===");
        Serial.print("KEY: ");
        Serial.println(NODE_KEY);
        Serial.print("NAME: ");
        Serial.println(NODE_NUMBER);
        Serial.print("BT NAME: FloodGuard_");
        Serial.println(NODE_KEY.substring(NODE_KEY.length() - 4));
        Serial.print("INTRUDER COUNT: ");
        Serial.println(intruderCount);
        Serial.println("==================");
      } else if (userMsg == "KEYS") {
        Serial.println("=== VALID KEYS ===");
        for (int i = 0; i < VALID_KEY_COUNT; i++) {
          Serial.println(VALID_KEYS[i]);
        }
        Serial.println("==================");
      } else {
        sendLoRaMessage(userMsg, "SERIAL");
      }
    }
  }
  
  // LoRa receive
  while (LoRaSerial.available()) {
    char c = LoRaSerial.read();
    if (c == '\n') {
      if (rxBuffer.length() > 0) {
        processReceived(rxBuffer);
        rxBuffer = "";
      }
    } else if (c != '\r') {
      rxBuffer += c;
    }
  }
  
  delay(10);
}

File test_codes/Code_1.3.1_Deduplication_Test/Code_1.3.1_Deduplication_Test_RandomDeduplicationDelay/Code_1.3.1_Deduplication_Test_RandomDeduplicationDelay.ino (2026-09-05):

#include <Arduino.h>

/* ---------- Pin Definitions (On-board D names) ---------- */
#define LORA_TX   16   // GPIO16 (D16) → AS32 TXD
#define LORA_RX   17   // GPIO17 (D17) → AS32 RXD
#define LORA_MD0  25   // GPIO25 (D25)
#define LORA_MD1  26   // GPIO26 (D26)
#define LORA_AUX  27   // GPIO27 (D27)

/* ---------- UART ---------- */
HardwareSerial LoRaSerial(2);

/* ---------- Deduplication Settings ---------- */
#define MAX_NODES            10
#define DEDUP_WINDOW_MS     5000   // 5s test window

/* ---------- Random Rebroadcast Delay ---------- */
#define REBROADCAST_MIN_MS  1000
#define REBROADCAST_MAX_MS 10000

/* ---------- Dedup Table ---------- */
typedef struct {
  String nodeId;
  uint16_t lastSeq;
  unsigned long lastSeen;
} DedupEntry;

DedupEntry dedupTable[MAX_NODES];
uint8_t dedupCount = 0;

/* ---------- Prototypes ---------- */
bool isDuplicate(String nodeId, uint16_t seq);
void setAS32GeneralMode();

/* ============================================================
   SETUP
   ============================================================ */
void setup() {
  Serial.begin(115200);
  delay(1000);

  pinMode(LORA_MD0, OUTPUT);
  pinMode(LORA_MD1, OUTPUT);
  pinMode(LORA_AUX, INPUT);

  setAS32GeneralMode();

  LoRaSerial.begin(9600, SERIAL_8N1, LORA_RX, LORA_TX);

  randomSeed(esp_random());  // ESP32 hardware RNG

  Serial.println("=== Code 1.3.1 : Dedup + Random Rebroadcast ===");
}

/* ============================================================
   LOOP
   ============================================================ */
void loop() {
  if (LoRaSerial.available()) {
    String packet = LoRaSerial.readStringUntil('\n');
    packet.trim();

    Serial.print("RX: ");
    Serial.println(packet);

    int p1 = packet.indexOf('|');
    int p2 = packet.indexOf('|', p1 + 1);

    if (p1 == -1 || p2 == -1) {
      Serial.println("Invalid packet → DROPPED");
      return;
    }

    String nodeId = packet.substring(0, p1);
    uint16_t seq  = packet.substring(p1 + 1, p2).toInt();

    if (isDuplicate(nodeId, seq)) {
      Serial.println("Duplicate → DROPPED");
    } else {
      Serial.println("New packet → ACCEPTED");

      // Random rebroadcast delay
      unsigned long delayMs =
        random(REBROADCAST_MIN_MS, REBROADCAST_MAX_MS + 1);

      Serial.print("Rebroadcasting in ");
      Serial.print(delayMs / 1000.0);
      Serial.println(" seconds");

      delay(delayMs);

      LoRaSerial.println(packet);  // Rebroadcast
      Serial.println("Packet REBROADCASTED");
    }

    Serial.println("--------------------------------");
  }
}

/* ============================================================
   Deduplication Logic (Time-based)
   ============================================================ */
bool isDuplicate(String nodeId, uint16_t seq) {
  unsigned long now = millis();

  for (int i = 0; i < dedupCount; i++) {
    if (dedupTable[i].nodeId == nodeId &&
        dedupTable[i].lastSeq == seq) {

      if (now - dedupTable[i].lastSeen < DEDUP_WINDOW_MS) {
        return true;
      } else {
        dedupTable[i].lastSeen = now;
        return false;
      }
    }
  }

  if (dedupCount < MAX_NODES) {
    dedupTable[dedupCount++] = { nodeId, seq, now };
  }

  return false;
}

/* ============================================================
   AS32 General Mode (MD0=0, MD1=0)
   ============================================================ */
void setAS32GeneralMode() {
  digitalWrite(LORA_MD0, LOW);  // D25
  digitalWrite(LORA_MD1, LOW);  // D26
  delay(10);
}

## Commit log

2026-09-05 Publish attributed RescueMesh source snapshot with safe local configuration
    [CE3V3SE_container v2.3mf, Load Sharing PCB.kicad_pcb, Load Sharing PCB.kicad_sch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]
2026-09-05 Feature original RescueMesh prototype photograph

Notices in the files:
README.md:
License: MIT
